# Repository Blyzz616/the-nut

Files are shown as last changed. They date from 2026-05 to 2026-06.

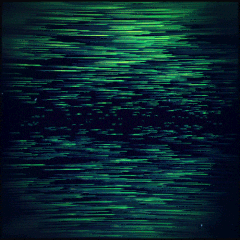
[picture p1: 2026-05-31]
gifs/04.gif

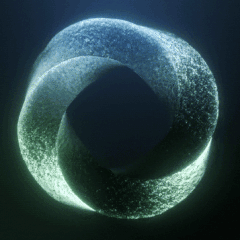
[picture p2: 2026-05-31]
gifs/09.gif

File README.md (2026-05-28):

# the nut

A smart poker card guard with a round touch display, blind timer, game timer, animated screens, and battery indicator — built on an ESP32-C6 in a 3D-printed enclosure.

---

## The Idea

Keep your cards protected and stay on top of the game. **the nut** sits on your hole cards and shows you what matters: how long until the blinds go up, how long you've been at the table, sick animations — all on a circular IPS touch display, in a puck-sized enclosure.

---

## Hardware

### Microcontroller

[Seeed Studio XIAO ESP32-C6](https://www.seeedstudio.com/Seeed-Studio-XIAO-ESP32C6-p-5884.html)

Thumb-sized ESP32-C6 with Wi-Fi 6, BLE 5.0, Zigbee, and Thread. Onboard USB-C charging circuit handles the LiPo directly — no extra charging module needed.

- **MCU**: ESP32-C6 (RISC-V single-core, 160MHz)
- **Flash**: 4MB
- **Wireless**: Wi-Fi 6 · BLE 5.0 · Zigbee · Thread
- **Charging**: USB-C, onboard TP4054 IC
- **Size**: 21 × 17.5mm

### Display

[EC Buying 1.28" Round Touch TFT Module](https://www.amazon.ca/dp/B0DLN33VQ5)

1.28-inch circular IPS display with capacitive touch. SPI display interface, I2C touch interface. No SD card slot — animations are procedural or cached to LittleFS.

- **Display driver**: GC9A01 (SPI)
- **Touch driver**: CST816D (I2C)
- **Resolution**: 240 × 240
- **Colors**: 65K RGB
- **Display area**: Ø32.4mm
- **Working voltage**: 3.3V / 5V
- **Module size**: 42.1 × 43 × 11.5mm
- **Interface**: MX1.25-8P (display) + MX1.25-4P (touch)

### Battery

[1100mAh 3.7V LiPo](https://www.amazon.ca/dp/B093G9K1D6)

Soldered directly to the `BAT+` and `GND` pads on the underside of the XIAO. Charges via USB-C through the onboard IC — no unplugging required.

- **Capacity**: 1100mAh
- **Voltage**: 3.7V nominal
- **Connection**: Direct solder to XIAO BAT pads

---

## Wiring

| Display pin | XIAO ESP32-C6 | Notes |
|---|---|---|
| VIN | 3V3 | Regulated 3.3V from onboard LDO |
| GND | GND | |
| SCL | GPIO6 | SPI clock |
| SDA | GPIO7 | SPI MOSI |
| RES | GPIO2 | Display reset |
| DC | GPIO3 | Data/command select |
| CS | GPIO20 | Chip select |
| BLK | GPIO21 | Backlight (or tie to 3V3 for always-on) |
| TP_SCL | GPIO22 | Touch I2C clock |
| TP_SDA | GPIO23 | Touch I2C data |
| TP_RST | GPIO1 | Touch reset |
| TP_INT | GPIO0 | Touch interrupt |

> **Note:** Battery connects to BAT+ and GND pads on the underside of the XIAO — not the 3V3 pin. Use the 3V3 pin only for powering the display.

---

## Display Screens

All timers run continuously in the background regardless of which screen is active. Swipe or double-tap to move between screens.

| Screen | Description |
|---|---|
| **Blinds timer** | Large countdown arc showing time until next blind level, current and next level |
| **Game timer** | Total session elapsed time, start time, estimated end |
| **Animated screen** | Looping procedural animation — cards, chips, flames, lava-lamp, matrix rain, etc |
| **Session stats** | Hands per hour, time at table, break reminders |
| **Clock** | Large watch-face style clock, NTP synced via Wi-Fi |
| **Battery** | Circular arc gauge, percentage, voltage, estimated hours remaining |

A permanent thin battery arc is drawn at the outer edge of the display on every screen, cycling green → yellow → red.

---

## Touch Gestures

| Gesture | Action |
|---|---|
| Single tap | Interact / confirm |
| Double tap | Next screen |
| Swipe | Previous / next screen |
| Long press | In-app menu / settings |
| 7-second hold on boot | Start reboot |
| Hold screen during boot | Enter bootloader mode (for firmware flashing) |

---

## Boot Sequence

If the screen is being touched, reboot into boot-loader for updating firmware.

If normal power up - no touch, the device tries each configured Wi-Fi network in order, stopping as soon as one connects:

```cpp
const char* networks[][2] = {
  {"HomeSSID",     "password1"},
  {"PhoneHotspot", "password2"},
  {"VenueWifi",    "password3"},
};
```

Once connected:
- NTP time sync
- Fetch updated config JSON (blind schedule, settings) from configured URL
- Fall back to locally cached LittleFS config if offline

---

## Firmware Update (Bootloader Mode)

Hold finger on screen at power-on. The backlight will blink 3 times to confirm, then the device enters bootloader mode. Flash normally via Arduino IDE or `esptool.py` over USB-C.

---

## Software Stack

- **[LVGL](https://lvgl.io)** — UI framework, arc widgets, animation engine, touch input handling
- **[SquareLine Studio](https://squareline.io)** — drag-and-drop UI layout, exports LVGL C code
- **LittleFS** — local filesystem for config and cached assets
- **ArduinoOTA** — over-the-air firmware updates over Wi-Fi
- **NTP** — time sync on connect

---

## Enclosure

3D printed. Target dimensions: ~50mm diameter, ~15–18mm tall. USB-C port flush to the side wall.

**Interior stack (bottom to top):**
1. Battery
2. XIAO ESP32-C6
3. Display module (face up, flush with top surface)

Material: Black PLA. Snap-fit or M2 screws for the lid.

---

## Expected Investment

| Item | Cost (CAD) |
|---|---|
| [XIAO ESP32-C6](https://www.seeedstudio.com/Seeed-Studio-XIAO-ESP32C6-p-5884.html) | ~$8 |
| [1.28" Round Touch Display](https://www.amazon.ca/dp/B0DLN33VQ5) | ~$38 |
| [1100mAh LiPo Battery](https://www.amazon.ca/dp/B093G9K1D6) | ~$12 |
| 3D printed enclosure (filament + iterations) | ~$2 |
| Miscellaneous (wire, solder, connectors) | ~$2 |
| **Total** | **~$62** |

---

## Project Status

- [x] Hardware selected
- [x] Wiring defined
- [x] Boot sequence designed
- [x] Screen layout planned
- [ ] Enclosure design
- [ ] LVGL screen implementation
- [ ] Wi-Fi / NTP / OTA
- [ ] Blind schedule config format
- [ ] Animation screens
- [ ] Final assembly

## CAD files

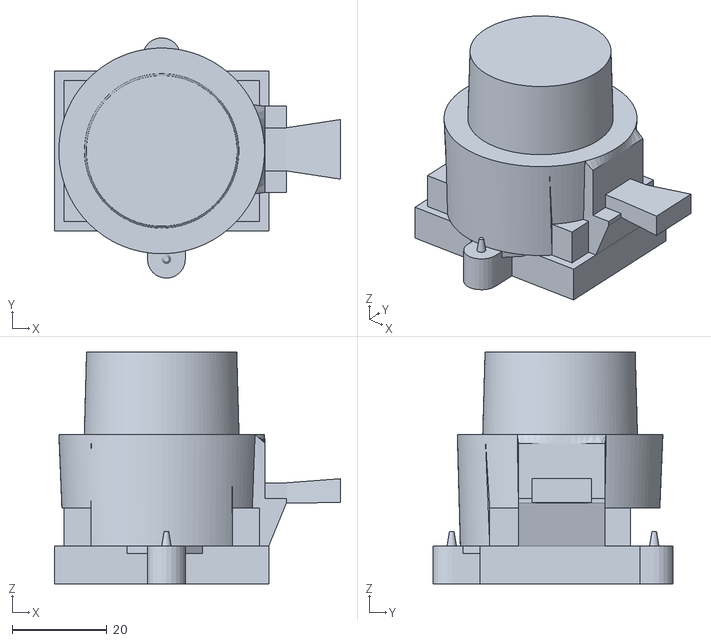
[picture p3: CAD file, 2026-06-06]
3d/bottom-loader0.10.stl
60.3 x 50.7 x 48.8

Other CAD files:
3d/v0.13.stl

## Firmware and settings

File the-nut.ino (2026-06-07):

#include <Arduino_GFX_Library.h>
#include <Wire.h>
#include <WiFi.h>
#include <WiFiMulti.h>
#include <NTPClient.h>
#include <WiFiUdp.h>
#include "config.h"
#include "state_machine.h"
#include "secrets.h"

enum class Gesture { NONE, TAP, DOUBLE_TAP, SWIPE_LEFT, SWIPE_RIGHT };

// ── Display ───────────────────────────────────────────────────────────────────
Arduino_DataBus *bus = new Arduino_ESP32SPI(PIN_DC, PIN_CS, PIN_SCLK, PIN_MOSI, GFX_NOT_DEFINED);
Arduino_GFX *tft = new Arduino_GC9A01(bus, PIN_RST, 0, true);
// Canvas buffers everything in RAM, flushed to display in one shot — eliminates flicker
Arduino_Canvas *gfx = new Arduino_Canvas(240, 240, tft);

// ── Globals ───────────────────────────────────────────────────────────────────
GameState gGame;
AppState  gApp;

WiFiMulti wifiMulti;
WiFiUDP   ntpUDP;
NTPClient timeClient(ntpUDP, NTP_SERVER, NTP_OFFSET_SEC, NTP_INTERVAL_MS);

// ── Touch ─────────────────────────────────────────────────────────────────────
#define CST816_ADDR 0x15

void touchInit() {
    pinMode(PIN_TP_RST, OUTPUT);
    digitalWrite(PIN_TP_RST, LOW); delay(50);
    digitalWrite(PIN_TP_RST, HIGH); delay(200);
    Wire.begin(PIN_TP_SDA, PIN_TP_SCL);
}

bool touchRead(int16_t &x, int16_t &y) {
    Wire.beginTransmission(CST816_ADDR);
    Wire.write(0x02);
    Wire.endTransmission(false);
    if (Wire.requestFrom(CST816_ADDR, 1) != 1) return false;
    if (Wire.read() == 0) return false;
    Wire.beginTransmission(CST816_ADDR);
    Wire.write(0x03);
    Wire.endTransmission(false);
    if (Wire.requestFrom(CST816_ADDR, 4) != 4) return false;
    uint8_t xh = Wire.read(), xl = Wire.read();
    uint8_t yh = Wire.read(), yl = Wire.read();
    x = ((xh & 0x0F) << 8) | xl;
    y = ((yh & 0x0F) << 8) | yl;
    return true;
}

// ── Gesture detection ─────────────────────────────────────────────────────────
static bool     _wasDown     = false;
static int16_t  _downX = 0, _downY = 0;
static int16_t  _curX  = 0, _curY  = 0;
static uint32_t _downTime    = 0;
static uint32_t _lastTapTime = 0;

Gesture gestureUpdate() {
    int16_t x, y;
    bool down = touchRead(x, y);
    if (down) {
        _curX = x; _curY = y;
        if (!_wasDown) {
            _wasDown = true;
            _downX = x; _downY = y;
            _downTime = millis();
        }
    } else if (_wasDown) {
        _wasDown = false;
        int16_t dx = _curX - _downX;
        if (abs(dx) > 40) return dx < 0 ? Gesture::SWIPE_LEFT : Gesture::SWIPE_RIGHT;
        uint32_t now = millis();
        if (now - _lastTapTime < 400) { _lastTapTime = 0; return Gesture::DOUBLE_TAP; }
        _lastTapTime = now;
        return Gesture::TAP;
    }
    return Gesture::NONE;
}

// ── Helpers ───────────────────────────────────────────────────────────────────
uint32_t levelDurationMs() {
    uint32_t mins = gGame.blindMinutes;
    if (gGame.speedMode) mins = (mins / 2 < 1) ? 1 : mins / 2;
    return mins * 60000UL;
}

int32_t levelSecsRemaining() {
    if (!gGame.running) return (int32_t)(levelDurationMs() / 1000);
    uint32_t elapsed;
    if (gGame.paused) {
        elapsed = gGame.pausedAt - gGame.levelStart;
    } else {
        elapsed = millis() - gGame.levelStart;
    }
    return (int32_t)(levelDurationMs() / 1000) - (int32_t)(elapsed / 1000);
}

// Millisecond-precision remaining for smooth ring
float levelFracRemaining() {
    if (!gGame.running) return 1.0f;
    uint32_t dur = levelDurationMs();
    uint32_t elapsed = gGame.paused ? (gGame.pausedAt - gGame.levelStart) : (millis() - gGame.levelStart);
    if (elapsed >= dur) return 0.0f;
    return (float)(dur - elapsed) / (float)dur;
}

void togglePause() {
    if (!gGame.running || gGame.overtime) return;
    if (gGame.paused) {
        // Resume — shift levelStart forward by how long we were paused
        gGame.levelStart += millis() - gGame.pausedAt;
        gGame.paused = false;
    } else {
        gGame.pausedAt = millis();
        gGame.paused = true;
    }
}

void toggleSpeedMode() {
    if (!gGame.running || gGame.overtime) {
        gGame.speedMode = !gGame.speedMode;
        return;
    }
    // Calculate elapsed time so far at current speed
    uint32_t now = gGame.paused ? gGame.pausedAt : millis();
    uint32_t elapsed = now - gGame.levelStart;

    gGame.speedMode = !gGame.speedMode;

    // Adjust levelStart so remaining time halves or doubles instantly
    // New elapsed = old elapsed * (newDuration / oldDuration)
    // Since duration halves on speed-on and doubles on speed-off, elapsed scales same way
    if (gGame.speedMode) {
        // Switched to speed — elapsed effectively doubles (we're further into the shorter level)
        uint32_t newElapsed = elapsed * 2;
        gGame.levelStart = now - newElapsed;
    } else {
        // Switched off speed — elapsed halves (we're less far into the longer level)
        uint32_t newElapsed = elapsed / 2;
        gGame.levelStart = now - newElapsed;
    }
    if (gGame.paused) gGame.pausedAt = now; // keep pausedAt consistent
}

// ── Drawing helpers ───────────────────────────────────────────────────────────
void clearScreen() { gfx->fillScreen(COL_BG); }

void drawCenteredText(const char* text, int y, int size, uint16_t color) {
    gfx->setTextSize(size);
    gfx->setTextColor(color);
    int16_t tx = DISPLAY_CX - strlen(text) * 3 * size;
    gfx->setCursor(tx, y);
    gfx->print(text);
}

// Fit text into w pixels, returns text size 1-4
uint8_t fitTextSize(const char* text, int w) {
    for (uint8_t s = 4; s >= 1; s--) {
        if ((int)strlen(text) * 6 * s <= w) return s;
    }
    return 1;
}

void drawButton(int x, int y, int w, int h, const char* label,
                uint16_t bg=COL_DARKGREY, uint16_t fg=COL_WHITE, int pad=2) {
    gfx->fillRoundRect(x+pad, y+pad, w-pad*2, h-pad*2, 6, bg);
    uint8_t ts = fitTextSize(label, w - pad*2 - 4);
    gfx->setTextSize(ts);
    gfx->setTextColor(fg);
    int16_t tx = x + w/2 - strlen(label)*3*ts;
    int16_t ty = y + h/2 - 4*ts;
    gfx->setCursor(tx, ty);
    gfx->print(label);
}

// Interpolate between two RGB565 colours
uint16_t lerpColor(uint16_t a, uint16_t b, float t) {
    uint8_t ar = (a >> 11) & 0x1F, ag = (a >> 5) & 0x3F, ab = a & 0x1F;
    uint8_t br = (b >> 11) & 0x1F, bg = (b >> 5) & 0x3F, bb = b & 0x1F;
    uint8_t r = ar + (int)((br-ar)*t);
    uint8_t g = ag + (int)((bg-ag)*t);
    uint8_t bv= ab + (int)((bb-ab)*t);
    return (r<<11)|(g<<5)|bv;
}

// Smooth ring: fraction=1.0 full, 0.0 empty
// Colour: green → blue → red as fraction decreases
void drawRing(float fraction) {
    float endDeg = 360.0f * fraction;
    int cx = DISPLAY_CX, cy = DISPLAY_CY, r1 = 118, r2 = 110;

    // Colour based on fraction
    uint16_t col;
    if (fraction > 0.1f) {
        // green (1.0) → blue (0.1): t goes 0→1
        float t = 1.0f - ((fraction - 0.1f) / 0.9f);
        col = lerpColor(0x07E0, 0x001F, t); // green → blue
    } else {
        // blue (0.1) → red (0.0): t goes 0→1
        float t = 1.0f - (fraction / 0.1f);
        col = lerpColor(0x001F, 0xF800, t); // blue → red
    }

    for (int deg = 0; deg < (int)endDeg; deg++) {
        float rad = (deg - 90) * DEG_TO_RAD;
        float cs = cos(rad), sn = sin(rad);
        for (int r = r2; r <= r1; r++) {
            gfx->drawPixel(cx + (int)(r*cs), cy + (int)(r*sn), col);
        }
    }
}

void clearRing() {
    // Erase ring area by redrawing black
    int cx = DISPLAY_CX, cy = DISPLAY_CY, r1 = 118, r2 = 110;
    for (int deg = 0; deg < 360; deg++) {
        float rad = (deg - 90) * DEG_TO_RAD;
        float cs = cos(rad), sn = sin(rad);
        for (int r = r2; r <= r1; r++) {
            gfx->drawPixel(cx + (int)(r*cs), cy + (int)(r*sn), COL_BG);
        }
    }
}

// ── Scene draws ───────────────────────────────────────────────────────────────
void drawBlindTimer() {
    int32_t secs = levelSecsRemaining();
    uint32_t now = millis();

    if (gGame.overtime) {
        gfx->fillScreen(COL_BG);
        uint32_t elapsed = (now - gGame.levelStart) - levelDurationMs();
        uint32_t s = elapsed / 1000;
        char buf[12];
        snprintf(buf, sizeof(buf), "%02lu:%02lu", s/60, s%60);
        drawCenteredText("OverTime", 72, 2, COL_RED);
        drawCenteredText(buf, 100, 4, COL_RED);
        drawCenteredText("double-tap for menu", 170, 1, COL_DARKGREY);
        return;
    }

    if (secs < 0) secs = 0;

    // ── New round intro: first 5 seconds, flash white/black every 500ms ──────
    uint32_t introElapsed = now - gGame.roundStartMs;
    bool inIntro = (gGame.running && !gGame.paused && introElapsed < 5000);

    // ── End of round: last 3 seconds, flash red/black every 500ms ────────────
    bool inOutro = (gGame.running && !gGame.paused && !inIntro &&
                    secs <= 3 && secs > 0);

    if (inIntro) {
        gfx->fillScreen(COL_WHITE);

        if (gGame.hasValues && gGame.currentRound < gGame.numRounds) {
            uint32_t sb = gGame.rounds[gGame.currentRound].smallBlind;
            uint32_t bb = gGame.rounds[gGame.currentRound].bigBlind;

            char sbuf[12], bbuf[12];
            snprintf(sbuf, sizeof(sbuf), "%lu", sb);
            snprintf(bbuf, sizeof(bbuf), "%lu", bb);

            bool stacked = (strlen(sbuf) >= 3 || strlen(bbuf) >= 3);

            if (stacked) {
                // Three lines: SB, /, BB — centered, large
                drawCenteredText(sbuf, 60,  4, COL_BG);
                drawCenteredText("/",  108, 4, COL_BG);
                drawCenteredText(bbuf, 156, 4, COL_BG);
            } else {
                // Single line: "SB / BB"
                char line[20];
                snprintf(line, sizeof(line), "%s / %s", sbuf, bbuf);
                // Pick size to fit
                uint8_t ts = 4;
                while (ts > 1 && (int)strlen(line) * 6 * ts > 200) ts--;
                drawCenteredText(line, 100, ts, COL_BG);
            }
        } else {
            // Timer-only game — just show "Go!"
            drawCenteredText("Go!", 100, 4, COL_BG);
        }
        return;
    }

    if (inOutro) {
        uint32_t levelElapsed = now - gGame.levelStart;
        uint32_t durMs = levelDurationMs();
        uint32_t remMs = (levelElapsed < durMs) ? (durMs - levelElapsed) : 0;
        bool flashOn = ((remMs % 1000) > 500); // first half=red, second half=black
        gfx->fillScreen(flashOn ? COL_RED : COL_BG);
        uint16_t textCol = flashOn ? COL_BG : COL_WHITE;

        char buf[8];
        snprintf(buf, sizeof(buf), "%02d:%02d", (int)(secs/60), (int)(secs%60));
        drawCenteredText(buf, 96, 6, textCol);
        return;
    }

    // ── Normal display ────────────────────────────────────────────────────────
    gfx->fillScreen(COL_BG);

    if (gGame.hasValues && gGame.currentRound < gGame.numRounds) {
        char sb[20];
        snprintf(sb, sizeof(sb), "$%lu / $%lu",
                 gGame.rounds[gGame.currentRound].smallBlind,
                 gGame.rounds[gGame.currentRound].bigBlind);
        drawCenteredText(sb, 58, 2, COL_GREY);
    }

    char buf[8];
    snprintf(buf, sizeof(buf), "%02d:%02d", (int)(secs/60), (int)(secs%60));
    uint16_t timerCol = gGame.paused ? COL_ORANGE : COL_WHITE;
    drawCenteredText(buf, 82, 6, timerCol);

    if (gGame.paused) drawCenteredText("PAUSED", 144, 2, COL_ORANGE);
    if (gGame.numRounds > 0) {
        char rnd[16];
        snprintf(rnd, sizeof(rnd), "Round %d/%d", gGame.currentRound+1, gGame.numRounds);
        drawCenteredText(rnd, gGame.paused ? 166 : 148, 2, COL_GREY);
    }

    // Ring
    if (gGame.running && !gGame.paused) {
        uint32_t durMs   = levelDurationMs();
        uint32_t elapsed = now - gGame.levelStart;
        uint32_t remMs   = (elapsed < durMs) ? (durMs - elapsed) : 0;
        uint32_t warnMs  = RING_WARN_SECS * 1000UL;

        float frac;
        uint16_t ringCol;
        if (remMs > warnMs) {
            frac    = (float)remMs / (float)durMs;
            ringCol = 0x2945;
        } else {
            frac    = (float)remMs / (float)warnMs;
            ringCol = lerpColor(0xF800, 0x07E0, frac);
        }

        int cx = DISPLAY_CX, cy = DISPLAY_CY, r1 = 118, r2 = 111;
        for (int deg = 0; deg < 360; deg++) {
            float rad = (deg - 90) * DEG_TO_RAD;
            float cs = cos(rad), sn = sin(rad);
            if ((float)deg / 360.0f <= frac) {
                for (int r = r2; r <= r1; r++)
                    gfx->drawPixel(cx+(int)(r*cs), cy+(int)(r*sn), ringCol);
            }
        }
    }
}
// Zones (from spec):
//   A: Wheel   x:40-116  y:40-200
//   B: Next    x:124-200 y:170-200
//   C: Value   x:124-200 y:70-170
//   D: Back    x:124-200 y:40-70
//   E: L-swipe x:0-32    y:70-170
//   F: R-swipe x:208-240 y:70-170

#define SW_WX1  40
#define SW_WX2  116
#define SW_VX1  124
#define SW_VX2  200
#define SW_Y1   40
#define SW_Y2   200
#define SW_BACK_Y2  70
#define SW_VAL_Y1   70
#define SW_VAL_Y2   170
#define SW_NEXT_Y1  170

int32_t blindStep(int32_t val) {
    if (val <   20) return 1;
    if (val <  100) return 5;
    if (val <  500) return 25;
    if (val < 2000) return 50;
    return 100;
}

struct ScrollInput {
    int32_t  value      = 0;
    int32_t  minVal     = 0;
    int32_t  maxVal     = 60;
    int32_t  step       = 1;
    float    pxPerUnit  = 4.0f;
    bool     wheelLeft  = true;
    float    velocity   = 0;
    float    wheelOffset= 0;
    bool     dragging   = false;
    int16_t  lastDragY  = 0;
    int16_t  totalDrag  = 0;  // track total drag distance to kill inertia on taps
    bool     blindMode  = false;
};

static ScrollInput _scroll;

void scrollInputInit(int32_t initVal, int32_t minV, int32_t maxV,
                     int32_t step, float pxPerUnit, bool blindMode=false) {
    _scroll.value       = initVal;
    _scroll.minVal      = minV;
    _scroll.maxVal      = maxV;
    _scroll.step        = step;
    _scroll.pxPerUnit   = pxPerUnit;
    _scroll.velocity    = 0;
    _scroll.wheelOffset = 0;
    _scroll.dragging    = false;
    _scroll.totalDrag   = 0;
    _scroll.blindMode   = blindMode;
}

void drawScrollWheel(int wx, int wy, int wx2, int wy2, float offset) {
    int ww = wx2 - wx, wh = wy2 - wy;
    int cy = wy + wh / 2;
    gfx->fillRoundRect(wx+2, wy+2, ww-4, wh-4, 10, COL_DARKGREY);

    // Dense ticks at top, sparse in middle, dense at bottom
    auto drawTicks = [&](int y0, int y1, bool dense) {
        int spacing = dense ? 8 : 18;
        int idx = 0;
        for (int y = y0; y <= y1; y += spacing, idx++) {
            if (y < wy+3 || y > wy2-3) continue;
            bool major = dense ? (idx % 2 == 0) : (idx % 3 == 0);
            int lw = major ? ww-12 : ww-24;
            uint16_t col = major ? COL_WHITE : COL_GREY;
            gfx->drawFastHLine(wx + (ww-lw)/2, y, lw, col);
        }
    };

    drawTicks(wy,    cy-18, true);
    drawTicks(cy-18, cy+18, false);
    drawTicks(cy+18, wy2,   true);
}

void flushDisplay() { gfx->flush(); }

void flashValueWhite(int vx1, int vx2) {
    int vw = vx2 - vx1, vh = SW_VAL_Y2 - SW_VAL_Y1;

    // Frame 1: white background, black text
    gfx->fillRoundRect(vx1+2, SW_VAL_Y1+2, vw-4, vh-4, 8, COL_WHITE);
    char buf[10];
    snprintf(buf, sizeof(buf), "%ld", _scroll.value);
    uint8_t ts = 4;
    while (ts > 1 && (int)strlen(buf) * 6 * ts > vw - 8) ts--;
    gfx->setTextColor(COL_BG);
    gfx->setTextSize(ts);
    gfx->setCursor(vx1 + vw/2 - strlen(buf)*3*ts, SW_VAL_Y1 + vh/2 - 4*ts);
    gfx->print(buf);
    flushDisplay();
    delay(120);

    // Frame 2: normal — dark background, white text
    gfx->fillRoundRect(vx1+2, SW_VAL_Y1+2, vw-4, vh-4, 8, COL_BG);
    gfx->setTextColor(COL_WHITE);
    gfx->setTextSize(ts);
    gfx->setCursor(vx1 + vw/2 - strlen(buf)*3*ts, SW_VAL_Y1 + vh/2 - 4*ts);
    gfx->print(buf);
    flushDisplay();
    delay(80);
}

void drawScrollValue(int vx, int vy, int vx2, int vy2, int32_t val) {
    int vw = vx2-vx, vh = vy2-vy;
    gfx->fillRoundRect(vx+2, vy+2, vw-4, vh-4, 8, COL_BG);

    char buf[10];
    snprintf(buf, sizeof(buf), "%ld", val);
    uint8_t ts = 4;
    while (ts > 1 && (int)strlen(buf) * 6 * ts > vw - 8) ts--;
    gfx->setTextColor(COL_WHITE);
    gfx->setTextSize(ts);
    int tx = vx + vw/2 - strlen(buf)*3*ts;
    int ty = vy + vh/2 - 4*ts;
    gfx->setCursor(tx, ty);
    gfx->print(buf);
}

void drawScrollScreen(const char* title, bool backEnabled, bool backVisible,
                      const char* nextLabel, const char* backLabel="Back") {
    clearScreen();

    // Title — centered, above y=40
    drawCenteredText(title, 14, 2, COL_WHITE);

    int wx1 = _scroll.wheelLeft ? SW_WX1 : SW_VX1;
    int wx2 = _scroll.wheelLeft ? SW_WX2 : SW_VX2;
    int vx1 = _scroll.wheelLeft ? SW_VX1 : SW_WX1;
    int vx2 = _scroll.wheelLeft ? SW_VX2 : SW_WX2;

    // A — Scroll wheel
    drawScrollWheel(wx1, SW_Y1, wx2, SW_Y2, _scroll.wheelOffset);

    // D — Back button (124,40 → 200,70)
    if (backVisible) {
        uint16_t backBg = backEnabled ? COL_RED : 0x7BEF; // grey for Timer
        uint16_t backFg = COL_WHITE;
        drawButton(vx1, SW_Y1, vx2-vx1, SW_BACK_Y2-SW_Y1, backLabel, backBg, backFg);
    }

    // C — Value display (124,70 → 200,170)
    drawScrollValue(vx1, SW_VAL_Y1, vx2, SW_VAL_Y2, _scroll.value);

    // B — Next button (124,170 → 200,200)
    if (nextLabel) drawButton(vx1, SW_NEXT_Y1, vx2-vx1, SW_Y2-SW_NEXT_Y1, nextLabel, COL_GREEN);
}

bool scrollUpdate(int16_t tx, int16_t ty, bool isDown) {
    bool changed = false;
    if (isDown) {
        if (!_scroll.dragging) {
            _scroll.dragging  = true;
            _scroll.lastDragY = ty;
            _scroll.totalDrag = 0;
            _scroll.velocity  = 0;
        } else {
            int16_t dy = _scroll.lastDragY - ty;
            if (abs(dy) > 0) {
                _scroll.totalDrag += abs(dy);
                int32_t step = _scroll.blindMode ? blindStep(_scroll.value) : _scroll.step;
                float pxPerStep = _scroll.blindMode ? (10.0f * sqrtf((float)step)) : _scroll.pxPerUnit;
                float units = (float)dy / pxPerStep;
                int32_t delta = (int32_t)(units) * step;
                if (delta != 0) {
                    // Only seed velocity if this was a real flick (>20px total drag)
                    if (_scroll.totalDrag > 20)
                        _scroll.velocity = units * 0.8f;
                    _scroll.value      += delta;
                    _scroll.value       = constrain(_scroll.value, _scroll.minVal, _scroll.maxVal);
                    _scroll.wheelOffset -= dy;
                    _scroll.lastDragY   = ty;
                    changed = true;
                }
            }
        }
    } else {
        if (_scroll.dragging) {
            _scroll.dragging = false;
            // Kill inertia if total drag was small — it was a tap or micro-movement
            if (_scroll.totalDrag < 20) _scroll.velocity = 0;
        }
        if (abs(_scroll.velocity) > 0.5f) {
            int32_t step = _scroll.blindMode ? blindStep(_scroll.value) : _scroll.step;
            float pxPerStep = _scroll.blindMode ? (10.0f * sqrtf((float)step)) : _scroll.pxPerUnit;
            _scroll.value      += (int32_t)(_scroll.velocity) * step;
            _scroll.value       = constrain(_scroll.value, _scroll.minVal, _scroll.maxVal);
            _scroll.wheelOffset -= _scroll.velocity * pxPerStep;
            _scroll.velocity   *= 0.85f;
            changed = true;
        } else {
            _scroll.velocity = 0;
        }
    }
    return changed;
}


void drawClock() {
    clearScreen();
    char buf[10];
    if (timeClient.isTimeSet())
        snprintf(buf, sizeof(buf), "%02d:%02d:%02d",
                 timeClient.getHours(), timeClient.getMinutes(), timeClient.getSeconds());
    else strcpy(buf, "--:--:--");
    drawCenteredText(buf, 104, 3, COL_WHITE);
}
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
void loop() {
    if (WiFi.status() == WL_CONNECTED) timeClient.update();

    updateGameLogic();

    // Continuous scroll handling
    bool scrollActive = (gApp.scene == Scene::SETUP_TIME || gApp.scene == Scene::SETUP_BLINDS);
    bool scrollChanged = false;
    if (scrollActive) {
        int wheelX1 = _scroll.wheelLeft ? SW_WX1 : SW_VX1;
        int wheelX2 = _scroll.wheelLeft ? SW_WX2 : SW_VX2;
        bool inWheel = (_wasDown && _curX >= wheelX1 && _curX <= wheelX2);
        scrollChanged = scrollUpdate(_curX, _curY, _wasDown && inWheel);
        // Also redraw during flash
        
    }

    Gesture g = gestureUpdate();
    Scene sceneBefore = gApp.scene;
    if (g != Gesture::NONE) {
        handleTouch(g, _downX, _downY);
        if (gApp.scene != sceneBefore) {
            if (gApp.scene == Scene::SETUP_TIME)
                scrollInputInit(gGame.blindMinutes, 1, 60, 1, 4.0f);
            _forceRedraw = true;
            _lastSecsShown = -999;
        }
    }

    uint32_t now = millis();
    bool sceneChanged = (gApp.scene != _lastScene);
    bool timeChanged = false;

    if (gApp.scene == Scene::BLIND_TIMER) {
        // Always redraw blind timer — smooth ring needs per-frame updates
        // Paused: no need to redraw every frame, just once
        if (!gGame.paused || sceneChanged || _forceRedraw)
            timeChanged = true;
    } else if (gApp.scene == Scene::CLOCK) {
        if (now - _lastDraw > 1000) timeChanged = true;
    }

    if (_forceRedraw || sceneChanged || timeChanged || scrollChanged) {
        _lastDraw    = now;
        _lastScene   = gApp.scene;
        _forceRedraw = false;
        switch (gApp.scene) {
            case Scene::BLIND_TIMER:  drawBlindTimer();  break;
            case Scene::CLOCK:        drawClock();        break;
            case Scene::MENU:         drawMenu();         break;
            case Scene::SETUP_TIME:   drawSetupTime();   break;
            case Scene::SETUP_BLINDS: drawSetupBlinds(); break;
            case Scene::START_GAME:   drawStartGame();   break;
        }
        flushDisplay();
    }

    delay(20);
}

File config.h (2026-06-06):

#pragma once

// Display pins
#define PIN_SCLK   D8
#define PIN_MOSI   D10
#define PIN_DC     D3
#define PIN_CS     D2
#define PIN_RST    D4
#define PIN_BL     D7

// Touch pins
#define PIN_TP_SDA D6
#define PIN_TP_SCL D5
#define PIN_TP_RST D0
#define PIN_TP_INT D1

// Display
#define DISPLAY_CX 120
#define DISPLAY_CY 120

// Colours (RGB565)
#define COL_BG       0x0000
#define COL_WHITE    0xFFFF
#define COL_GREEN    0x07E0
#define COL_RED      0xF800
#define COL_ORANGE   0xFD20
#define COL_GREY     0x7BEF
#define COL_DARKGREY 0x39E7
#define COL_RING     0x07E0

// Timing
#define RING_WARN_SECS 20

// NTP
#define NTP_SERVER      "pool.ntp.org"
#define NTP_OFFSET_SEC  -25200
#define NTP_INTERVAL_MS 10000
